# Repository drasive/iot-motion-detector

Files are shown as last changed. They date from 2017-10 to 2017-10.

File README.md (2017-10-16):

# iot-motion-detector

A $6 internet of things and easy to build motion detector.  

This implementation controls a Philips Hue light, but any IoT application can be implemented using the builtin WiFi adapter.

## Hardware
Name                                 | Type            | Price (USD) | Link
-------------------------------------|-----------------|-------------|-----
WeMos D1 mini V2.2.0 (ESP8266 board) | Microcontroller | 4.09        | [banggood.com](https://www.banggood.com/WeMos-D1-mini-V2_2_0-WIFI-Internet-Development-Board-Based-ESP8266-4MB-FLASH-ESP-12S-Chip-p-1143874.html)
HC-SR501                             | Motion detector | 1.95        | [banggood.com](https://www.banggood.com/HC-SR501-Human-Infrared-Sensor-Module-Including-Lens-p-972697.html)

Total cost: USD 6.03 (excluding shipping, recorded 2017-09-16)

### Required equipment
* Jumper wires
* Breadboard (prototyping)
* Soldering iron
* Micro USB cable (system power/ESP8266 programming)
* USB power adapter (system power)
* Computer (ESP8266 programming)

### Wiring
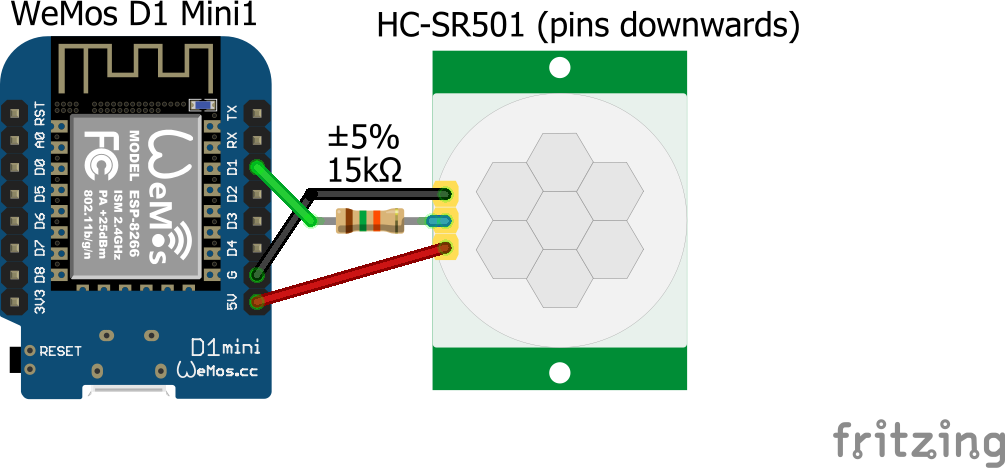
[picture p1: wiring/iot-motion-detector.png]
Wiring Plan


### HC-SR501 configuration
See http://henrysbench.capnfatz.com/henrys-bench/arduino-sensors-and-input/arduino-hc-sr501-motion-sensor-tutorial/.
It is recommended to set the time delay to the minimum as the software handles delays itself.

### Power Consumption
The values in this section are calculated, I do not have the required hardware to make measurements.

#### Standby
Sensing for motion, not sending/receiving over WiFi.

Component | State           | Power Draw (mA)
----------|-----------------|----------------
ESP8266   | Modem-Sleep [4] | 15
HC-SR501  | On              |  0.065

Total: 15.065mA

#### Active
Sensing for motion, sending/receiving over WiFi.

Component | State          | Power Draw (mA)
----------|----------------|----------------
ESP8266   | Tx 802.11b [4] | 170
HC-SR501  | On             |   0.065

Total: 170.065mA

### Using Different Hardware
You can quite easily build this project with other ESP8266 boards and motion sensors other than the HC-SR501.
When doing so, watch out for the following possible differences (list not complete):

Different ESP8266 board:
- No USB connector (power delivery, programming)
- No 5V output (power delivery to HC-SR501)

Motion sensor other than HC-SR501:
- Required voltage (power delivery)

## Software
### Configuration
Name                        | Type     | Default Value              | Description
----------------------------|----------|----------------------------|------------
light_on_duration           | uint32_t | 60 * 1000 (60s)            | Time to keep the lights on in milliseconds
nighttime_start             | uint16_t | 23 * 60 (23:00)            | Start of nighttime in minutes since midnight
nighttime_duration          | uint16_t | 7 * 60 (06:00)             | Duration of nighttime in minutes
hue_ip                      | char*    | -                          | Local IP Address of the Hue Bridge
hue_port                    | uint16_t | 80                         | Port of the Hue Bridge API
hue_timeout                 | uint16_t | 10 * 1000 (10s)            | Timeout for requests to the Hue Bridge in milliseconds
hue_user_id                 | char*    | -                          | ID of the Hue Bridge user for authentication*
hue_light_identifier        | char*    | lights/1                   | Identifier of the Hue light/lightgroup to control
hue_command_on_daytime      | char*    | {\"on\":true, \"bri\":254} | Command to turn the Hue light on during daytime
hue_command_on_nighttime    | char*    | {\"on\":true, \"bri\":1}   | Command to turn the Hue light on during nighttime
hue_command_off             | char*    | {\"on\":false}             | Command to turn the Hue light off
wifi_ssid                   | char*    | -                          | SSID of the WiFi network*
wifi_password               | char*    | -                          | Password for the Wifi network*
wifi_timeout                | uint16_t | 15 * 1000 (15s)            | Timeout for connecting to the WiFi network in milliseconds
ntp_host                    | char*    | pool.ntp.org               | Hostname of the NTP server
ntp_offset                  | int32_t  | 0                          | Offset from the UTC time in milliseconds
ntp_update_interval         | uint32_t | 24 * 60 * 60 * 1000 (24h)  | Interval of system clock synchronisation with NTP server
baud_rate                   | uint32_t | 115200                     | Baud rate for serial communication
pin_status_led              | uint8_t  | [LED_BUILTIN]              | Pin number of the status LED
pin_motion_sensor           | uint8_t  | 5                          | Pin number of the motion sensor (data pin)
motion_sensor_init_duration | uint32_t | 60 * 1000 (60s)            | Time until the motion sensor is ready for the first reading in milliseconds
debug                       | bool     | false                      | Output debug information

*Confidential information, keep private

### Libraries
- [ESP8266WiFi](https://github.com/esp8266/Arduino/tree/master/libraries/ESP8266WiFi)
- [NTPClient](https://github.com/arduino-libraries/NTPClient)

### Functionality
#### Status LED
The following states are communicated using the onboard LED:
- Initializing: LED is on, blinks once when it is done
- Shutdown: LED blinks 3 times long, then turns off
- Motion detected: LED is on
- No motion detected: LED is off

#### Initialization
After powering on the device gets everything ready for operation. 
This includes connecting to the WiFi network and waiting for the motion sensor initialization.
If any of these operations fail, shutdown is initiated. The shutdown reason is logged to the serial bus.
The amount of time required for initialization is usually bound by the configuration value of "motion_sensor_init_duration".

#### Shutdown
The device reduces power usage to a minimum. A power cycle is required to restart.
A shutdown can only occur during initialization (see section "Initialization").

#### Turning Light on
When motion is detected the light is turned on.

#### Turning Light off
When motion is not detected for the specified amount of time (configuration value "light_on_duration") the light is turned off.
When motion is detected again while the light is still on the timer is reset.

#### Daytime/Nighttime
Different on-commands can be defined for daytime/nighttime (configuration values "hue_command_on_daytime" and "hue_command_on_nighttime").
When and how long nighttime is can be configured (configuration values "nighttime_start" and "nighttime_duration").
The light state will not update if it is on during a datime/nighttime switch.

#### NTP Time Synchronization
The device periodically (configuration value "ntp_update_interval") updates its internal clock with an NTP server (configuration value "ntp_host").
This is a blocking operation and can slightly delay turning the light on/off.

#### Serial Bus
Information about interrupts, actions and requests are logged to the serial interface (USB port).
Additional debug information can be turned on (configuration value "debug").

### Arduino IDE Board Settings
Board: WeMos D1 R2 & mini  
CPU Frequency: 80 MHz  
Flash Size: 4M (3M SPIFFS)  
Upload Speed: 57600

### Improvement Ideas
- Support for OTA updating of configuration values

## Development Process
Project goal: Building a motion detector that can turn on Philips Hue lightbulbs when entering a room.

### Hardware selection
Shipping prices and durations were calculated for Switzerland.

#### Motion detector
Selection criteria:
* <= 5$ cost (including shipping and microcontroller integration)
* &gt;= 2m range
* &gt;= 60 degrees horizontal sensing range
* <= 1s detection delay
* <= 4 weeks shipping time
* Easy to use with microcontroller (documentation/tutorials)
* Low power consumption

Evaluated options:
* HC-SR501

The HC-SR501 passive infrared motion sensor satisfies all criteria and seems to be a hobbyist favorite.

#### Microcontroller
Selection criteria:
* <= 15$ cost (including shipping and adding WiFi functionality)
* <= 4 weeks shipping time
* Easy to use with motion sensor (documentation/tutorials)
* Easy to use with WiFi (documentation/tutorials)
* Easy to power (documentation/tutorials)
* Low power consumption

Evaluated options:
* Genuino MKR1000
* Arduino Uno
* Raspberry Pi
* ESP8266

The ESP8266 is the only evaluated option that satisfies the cost criteria,
has integrated WiFi and seems to be a hobbyist favorite.

### Powering the System
The system should be able to be powered by a single power cable or batteries.  

The ESP8266 is powered by a micro USB cable. This enables the use of a USB power adaptor and battery packs.  
The HC-SR501 is powered directly with 5V by the ESP8266.

### HC-SR501 False Positives
The HC-SR501 initially fired a lot of false positives. Putting a 15k Ohm resistor in the data line seems to have solved this problem (see section "Wiring").

## References
1. Similar project: https://www.reddit.com/r/esp8266/comments/5l94gl/motion_control_hue_lights_with_esp8266_and_pir/

1. ESP8266 programming: https://hackaday.com/2015/03/18/how-to-directly-program-an-inexpensive-esp8266-wifi-module/
1. ESP8266 programming with Arduino IDE: https://arduino-esp8266.readthedocs.io/en/latest/installing.html#instructions
1. ESP8266 power consumption: http://bbs.espressif.com/viewtopic.php?t=133
1. ESP8266 power saving: https://github.com/esp8266/Arduino/issues/1381

1. HC-SR501 configuration: http://henrysbench.capnfatz.com/henrys-bench/arduino-sensors-and-input/arduino-hc-sr501-motion-sensor-tutorial/

1. Philips Hue API: https://developers.meethue.com/documentation/getting-started

All references were viewed on 2017-09-16.

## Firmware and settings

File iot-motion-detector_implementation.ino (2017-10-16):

/*
  IoT Motion Detector v1.0.1
  A $6 internet of things and easy to build motion detector.

  See iot-motion-detector.ino for configuration.

  License:      MIT
  Repository:   https://github.com/drasive/iot-motion-detector
  Author:       Dimitri Vranken <me@dimitrivranken.com>
*/


// ===== Program =====
volatile uint32_t g_motion_last_detected_time = 0;
uint32_t g_light_last_turned_on_time = 0;
bool g_light_is_on = false;

WiFiUDP g_ntp_udp;
NTPClient g_ntp_client(g_ntp_udp, c_ntp_host, c_ntp_offset / 1000, 0);
uint32_t g_time_last_updated_time = 0;


void setup() {
  // Initialize
  pinMode(c_pin_status_led, OUTPUT);
  digitalWrite(c_pin_status_led, LOW);
  uint32_t boot_time = millis();

  Serial.begin(c_baud_rate);
  Serial.println();
  Serial.println(F("===== IoT Motion Detector v1.0.1 ====="));
  Serial.println(F("https://github.com/drasive/iot-motion-detector"));
  Serial.println(F("Dimitri Vranken <me@dimitrivranken.com>"));

  // Connect to WiFi network
  Serial.println();
  if (!ensure_wifi_connected(c_wifi_ssid, c_wifi_password)) {
    shut_down("Failed to connect to WiFi during setup");
  }

  // Update time
  Serial.println();
  g_ntp_client.begin();
  update_ntp_time(c_ntp_host, c_ntp_offset);
  g_time_last_updated_time = millis();

  // Wait for motion sensor initialization
  Serial.println();
  Serial.println("Waiting for motion sensor initialization");
  while (millis() - boot_time <= c_motion_sensor_init_duration) {
    delay(10);
  }

  // Finish
  Serial.println();
  Serial.println(F("Setup completed"));
  Serial.println();

  digitalWrite(c_pin_status_led, HIGH);
  delay(1 * 1000);

  // Register interrupts
  pinMode(c_pin_motion_sensor, INPUT);
  attachInterrupt(
    digitalPinToInterrupt(c_pin_motion_sensor),
    interrupt_handler_motion_sensor,
    CHANGE
  );
}

void loop() {
  // Ensure WiFi connection
  ensure_wifi_connected(c_wifi_ssid, c_wifi_password);

  // Handle detected motion
  bool motion_detected_yet = g_motion_last_detected_time != 0;
  bool motion_detected_recently = motion_detected_yet && millis() - g_motion_last_detected_time <= c_light_on_duration;
    
  if (motion_detected_yet && motion_detected_recently && !g_light_is_on) {
    // Motion was detected recently and light is off
    Serial.println();
    Serial.println(F("== Turning light on =="));

    int8_t command_status = is_daytime(g_ntp_client.getHours(), g_ntp_client.getMinutes(), c_nighttime_start, c_nighttime_duration)
      ? hue_send_command(c_hue_light_identifier, c_hue_command_on_daytime)
      : hue_send_command(c_hue_light_identifier, c_hue_command_on_nighttime);

    if (command_status == 1) {
      g_light_is_on = true;
      g_light_last_turned_on_time = millis();

      Serial.print(F("Response time: "));
      Serial.print(millis() - g_motion_last_detected_time);
      Serial.println(F(" ms"));
    }
  }
  else if (motion_detected_yet && !motion_detected_recently && g_light_is_on) {
    // Motion was NOT detected recently and light is on
    Serial.println();
    Serial.println(F("== Turning light off =="));
    int8_t command_status = hue_send_command(c_hue_light_identifier, c_hue_command_off);

    if (command_status == 1) {
      g_light_is_on = false;
    }
  }

  // Update time
  if (millis() - g_time_last_updated_time >= c_ntp_update_interval) {
    Serial.println();
    Serial.println(F("== Updating time =="));

    update_ntp_time(c_ntp_host, c_ntp_offset);
    g_time_last_updated_time = millis();
  }

  delay(10);
}

void interrupt_handler_motion_sensor() {
  bool motion_detected = digitalRead(c_pin_motion_sensor) == HIGH;

  digitalWrite(c_pin_status_led, motion_detected ? LOW : HIGH);
  if (motion_detected) {
    g_motion_last_detected_time = millis();
  }

  Serial.print("# Motion sensor interrupt: ");
  Serial.println(motion_detected ? F("Motion detected") : F("No motion detected"));
}


/*
 * Tries to connect to the specified WiFi network, if not already connected.
 * The return value indicates if the connection was successful.
 */
bool ensure_wifi_connected(const char* ssid, const char* password) {
  if (WiFi.status() == WL_CONNECTED) {
    return true;
  }

  Serial.println(F("Connecting to WiFi network"));
  print_name_value("SSID", ssid);
  print_name_value("Password", password);

  uint32_t connection_start_time = millis();
  WiFi.begin(ssid, password);
  while (WiFi.status() != WL_CONNECTED) {
    if (millis() - connection_start_time > c_wifi_timeout) {
      print_with_duration("Connecting to Wifi network failed", connection_start_time);
      return false;
    }

    delay(10); // Checking the WiFi status too quickly results in an error
  }
  print_with_duration("Connecting to Wifi network successful", connection_start_time);
  char ip_address[16];
  WiFi.localIP().toString().toCharArray(ip_address, sizeof(ip_address));
  print_name_value("IP address", ip_address);

  return true;
}

/* 
 * Sends a command to a Hue light.
 * 
 * Return values:
 *  1: Operation successful
 *  0: Operation not successful
 * -1: Failed to execute operation
 */
int8_t hue_send_command(const char* hue_light_identifier, const char* command) {
  Serial.println(F("Sending command to Hue light"));
  print_name_value("Light identifier", hue_light_identifier);
  print_name_value("Command", command);

  // Connect to Hue Bridge
  WiFiClient client;
  uint32_t connection_start_time = millis();
  if (!client.connect(c_hue_ip, c_hue_port)) {
    print_with_duration("Connecting to Hue Bridge failed", connection_start_time);
    return -1;
  }
  print_with_duration("Connecting to Hue Bridge successful", connection_start_time);

  // Send request
  client.println("PUT /api/" + String(c_hue_user_id) + "/" + String(hue_light_identifier) + "/state");
  client.println("Host: " + String(c_hue_ip) + ":" + String(c_hue_port));
  client.println("User-Agent: ESP8266/1.0");
  client.println("Connection: keep-alive");
  client.println("Content-Type: text/json; charset=\"utf-8\"");
  client.print("Content-Length: ");
  client.println(strlen(command));
  client.println();
  client.println(command);

  // Wait for response
  uint32_t request_sent_time = millis();
  while (client.available() == 0) {
    if (millis() - request_sent_time > c_hue_timeout) {
      print_with_duration("Response from Hue Bridge not received", request_sent_time);
      client.stop();
      return -1;
    }

    delay(10);
  }
  print_with_duration("Response from Hue Bridge received", request_sent_time);

  // Parse response
  int8_t operation_successful = 0;
  while(client.available()) {
    String line = client.readStringUntil('\r');
    if (c_debug) {
      Serial.print(line);
    }

    if (line.indexOf("\"success\":") != -1) {
      operation_successful = 1;
      break;
    }
  }
  if (c_debug) {
    Serial.println();
  }

  // Close connection
  client.stop();

  Serial.print(F("Command status: "));
  Serial.println(operation_successful ? F("Successful") : F("Failed"));

  return operation_successful;
}

/*
 * Synchronizes the system clock with an NTP server.
 */
void update_ntp_time(const char* ntp_host, const int32_t ntp_offset) {
  Serial.println(F("Requesting time from NTP server"));
  print_name_value("NTP Host", ntp_host);
  print_name_value("NTP Offset", String(ntp_offset));

  uint32_t request_sent_time = millis();
  g_ntp_client.forceUpdate();
  print_with_duration("Response from NTP server received", request_sent_time);

  Serial.print(F("System time: "));
  Serial.println(g_ntp_client.getFormattedTime());
}


// ===== Helpers =====
/*
 * Returns true if the specified time lies outside of the specified nighttime; false otherwise.
 */
bool is_daytime(
  const uint8_t current_hour, const uint8_t current_minute,
  const uint16_t nighttime_start, const uint16_t nighttime_duration) {
    uint16_t current_minutes = (current_hour * 60) + current_minute;
    uint16_t nighttime_end = (nighttime_start + nighttime_duration) % (24 * 60);
    
    if (nighttime_end < nighttime_start) {
      // Nighttime crosses over midnight
      return current_minutes < nighttime_start && current_minutes >= nighttime_end;
    }
    
    // Nighttime doesn't cross over midnight
    return current_minutes < nighttime_start || current_minutes >= nighttime_end;
}


/*
 * Prints a text with the time elapsed since the specified start time.
 */
void print_with_duration(const char* text, const uint32_t start_time) {
  Serial.print(text);
  Serial.print(F(" ("));
  Serial.print(millis() - start_time);
  Serial.println(F(" ms)"));
}

/*
 * Prints a name-value pair.
 */
void print_name_value(const char* name, const char* value) {
  Serial.print(name);
  Serial.print(F(": "));
  Serial.println(value);
}

/*
 * Prints a name-value pair.
 */
void print_name_value(const char* name, String value) {
  Serial.print(name);
  Serial.print(F(": "));
  Serial.println(value);
}

/*
 * Reduces power usage to a minimum.
 * A power cycle is required to restart.
 */
void shut_down(const char* reason) {
  Serial.println();
  Serial.print(F("Shutting down: "));
  Serial.println(reason);

  for (uint8_t i = 0; i < 3; i++) {
    digitalWrite(c_pin_status_led, HIGH);
    delay(1 * 1000);
    digitalWrite(c_pin_status_led, LOW);
    delay(1 * 2000);
  }

  digitalWrite(c_pin_status_led, HIGH);
  ESP.deepSleep(0);
}

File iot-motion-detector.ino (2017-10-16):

/*
  IoT Motion Detector v1.0.1
  A $6 internet of things and easy to build motion detector.

  See iot-motion-detector_implementation.ino for implementation.

  License:      MIT
  Repository:   https://github.com/drasive/iot-motion-detector
  Author:       Dimitri Vranken <me@dimitrivranken.com>
*/


// ===== Includes =====
#include <ESP8266WiFi.h>
#include <NTPClient.h>
#include <WiFiUdp.h>


// ===== Configuration =====
const uint32_t c_light_on_duration = 30 * 1000;                      // Time to keep the lights on in milliseconds
const uint16_t c_nighttime_start = 23 * 60;                          // Start of nighttime in minutes since midnight
const uint16_t c_nighttime_duration = 7 * 60;                        // Duration of nighttime in minutes

const char* c_hue_ip = "TO_BE_SET";                                  // Local IP Address of the Hue Bridge
const uint16_t c_hue_port = 80;                                      // Port of the Hue Bridge API
const uint16_t c_hue_timeout = 10 * 1000;                            // Timeout for requests to the Hue Bridge in milliseconds
const char* c_hue_user_id = "TO_BE_SET";                             // ID of the Hue Bridge user for authentication
const char* c_hue_light_identifier = "lights/1";                     // Identifier of the Hue light/lightgroup to control
const char* c_hue_command_on_daytime = "{\"on\":true, \"bri\":254}"; // Command to turn the Hue light on during daytime
const char* c_hue_command_on_nighttime = "{\"on\":true, \"bri\":1}"; // Command to turn the Hue light on during nighttime
const char* c_hue_command_off = "{\"on\":false}";                    // Command to turn the Hue light off

const char* c_wifi_ssid = "TO_BE_SET";                               // SSID of the WiFi network
const char* c_wifi_password = "TO_BE_SET";                           // Password for the Wifi network
const uint16_t c_wifi_timeout = 15 * 1000;                           // Timeout for connecting to the WiFi network in milliseconds

const char* c_ntp_host = "pool.ntp.org";                             // Hostname of the NTP server
const int32_t c_ntp_offset = 2 * 60 * 60 * 1000;                     // Offset from the UTC time in milliseconds
const uint32_t c_ntp_update_interval = 24 * 60 * 60 * 1000;          // Interval of system clock synchronisation with NTP server

const uint32_t c_baud_rate = 115200;                                 // Baud rate for serial communication
const uint8_t c_pin_status_led = LED_BUILTIN;                        // Pin number of the status LED
const uint8_t c_pin_motion_sensor = 5;                               // Pin number of the motion sensor (data pin)
const uint32_t c_motion_sensor_init_duration = 60 * 1000;            // Time until the motion sensor is ready for the first reading in milliseconds
const bool c_debug = false;                                          // Output debug information

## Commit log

2017-10-11 Created .fzz file
    [iot-motion-detector.fzz]
2017-10-13 Added wiring plan
    [iot-motion-detector.fzz]
2017-10-16 Fixed wiring diagram
    [iot-motion-detector.fzz]
2017-10-16 Using 15k Ohm resistor in data line
    [iot-motion-detector.fzz]
2017-10-16 Added resistor strength to wiring diagram
    [iot-motion-detector.fzz]
